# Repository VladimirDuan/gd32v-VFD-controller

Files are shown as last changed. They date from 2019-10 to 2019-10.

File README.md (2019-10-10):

# gd32v-VFD-controller

## The HNV-12SS62 VFD screen:

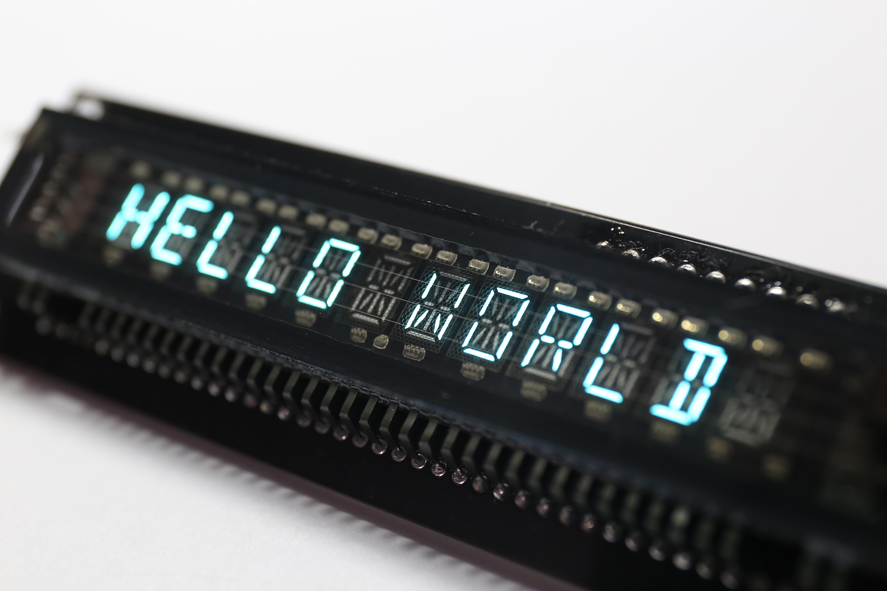
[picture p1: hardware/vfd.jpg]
VFD


## GD32V rv32imac microcontroller:

VFD_MCU

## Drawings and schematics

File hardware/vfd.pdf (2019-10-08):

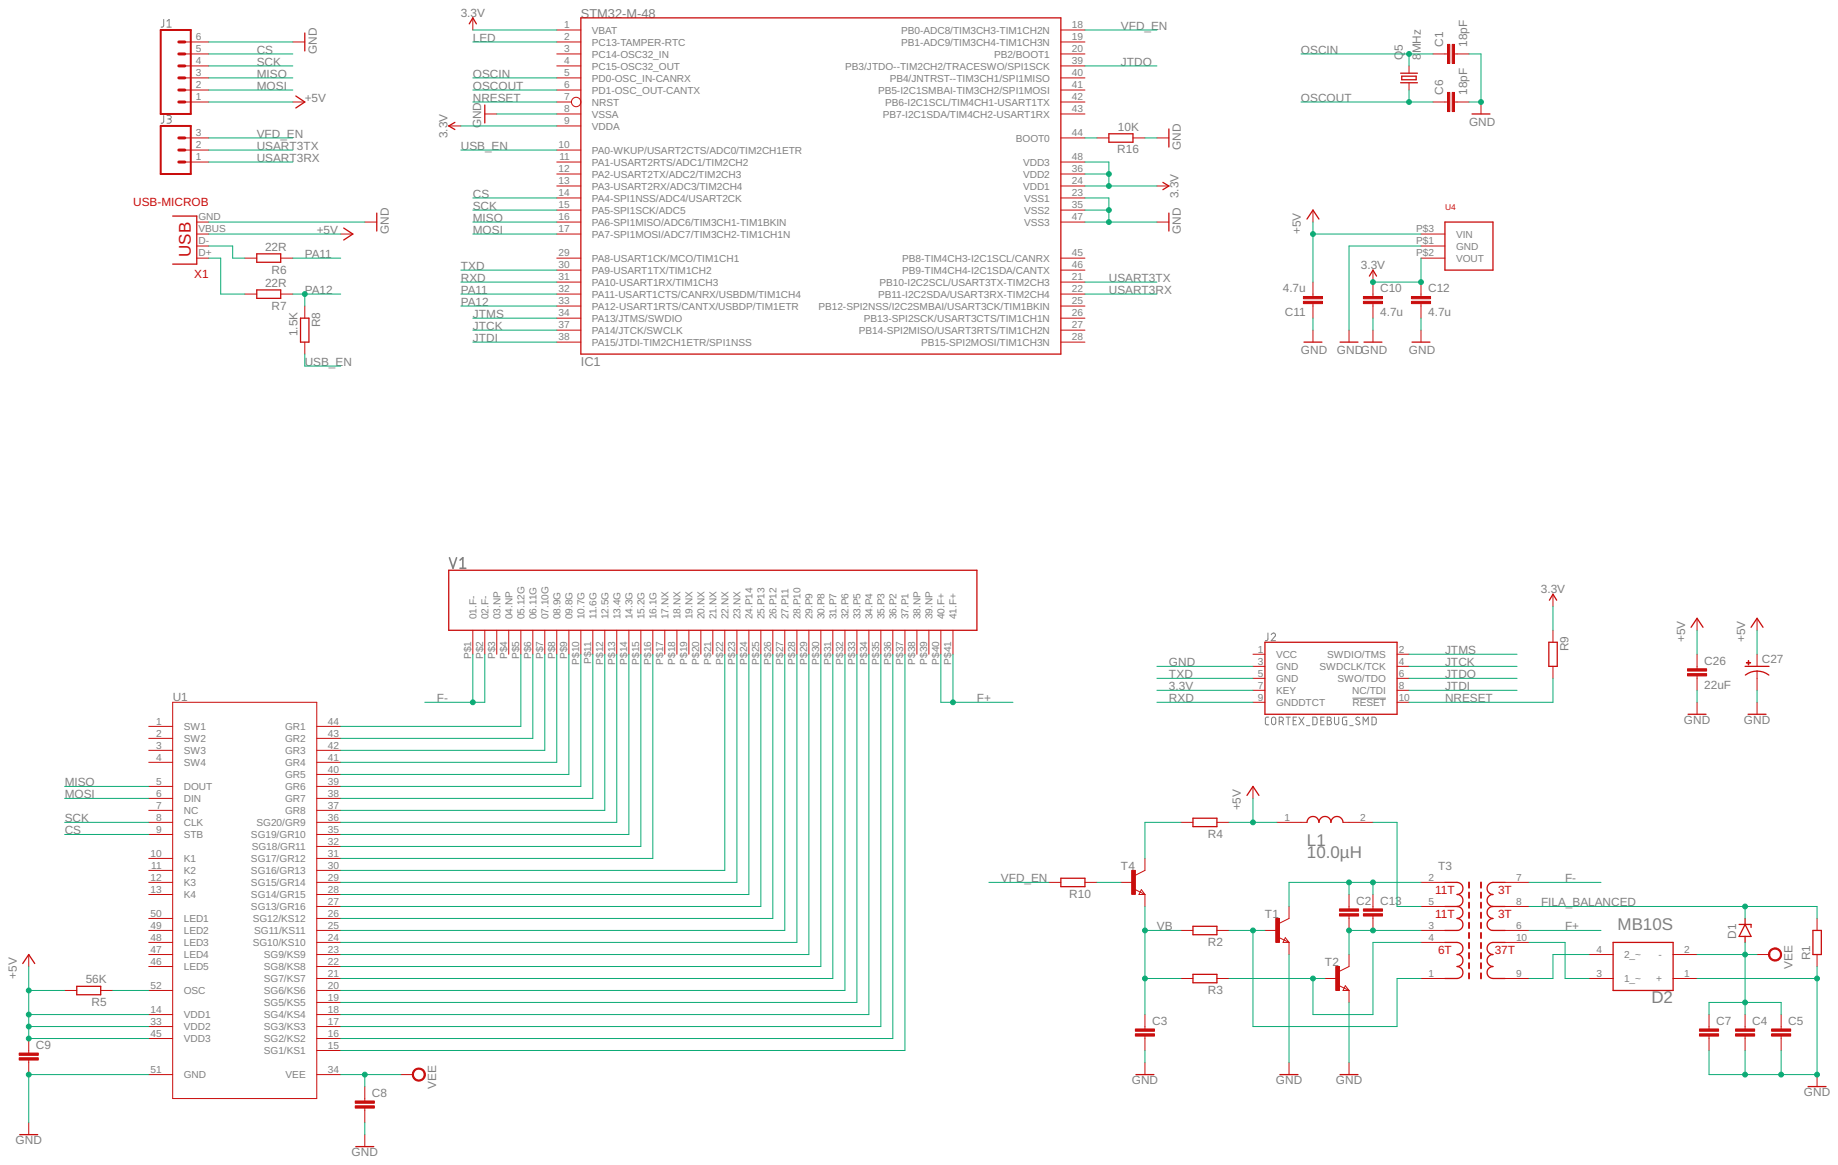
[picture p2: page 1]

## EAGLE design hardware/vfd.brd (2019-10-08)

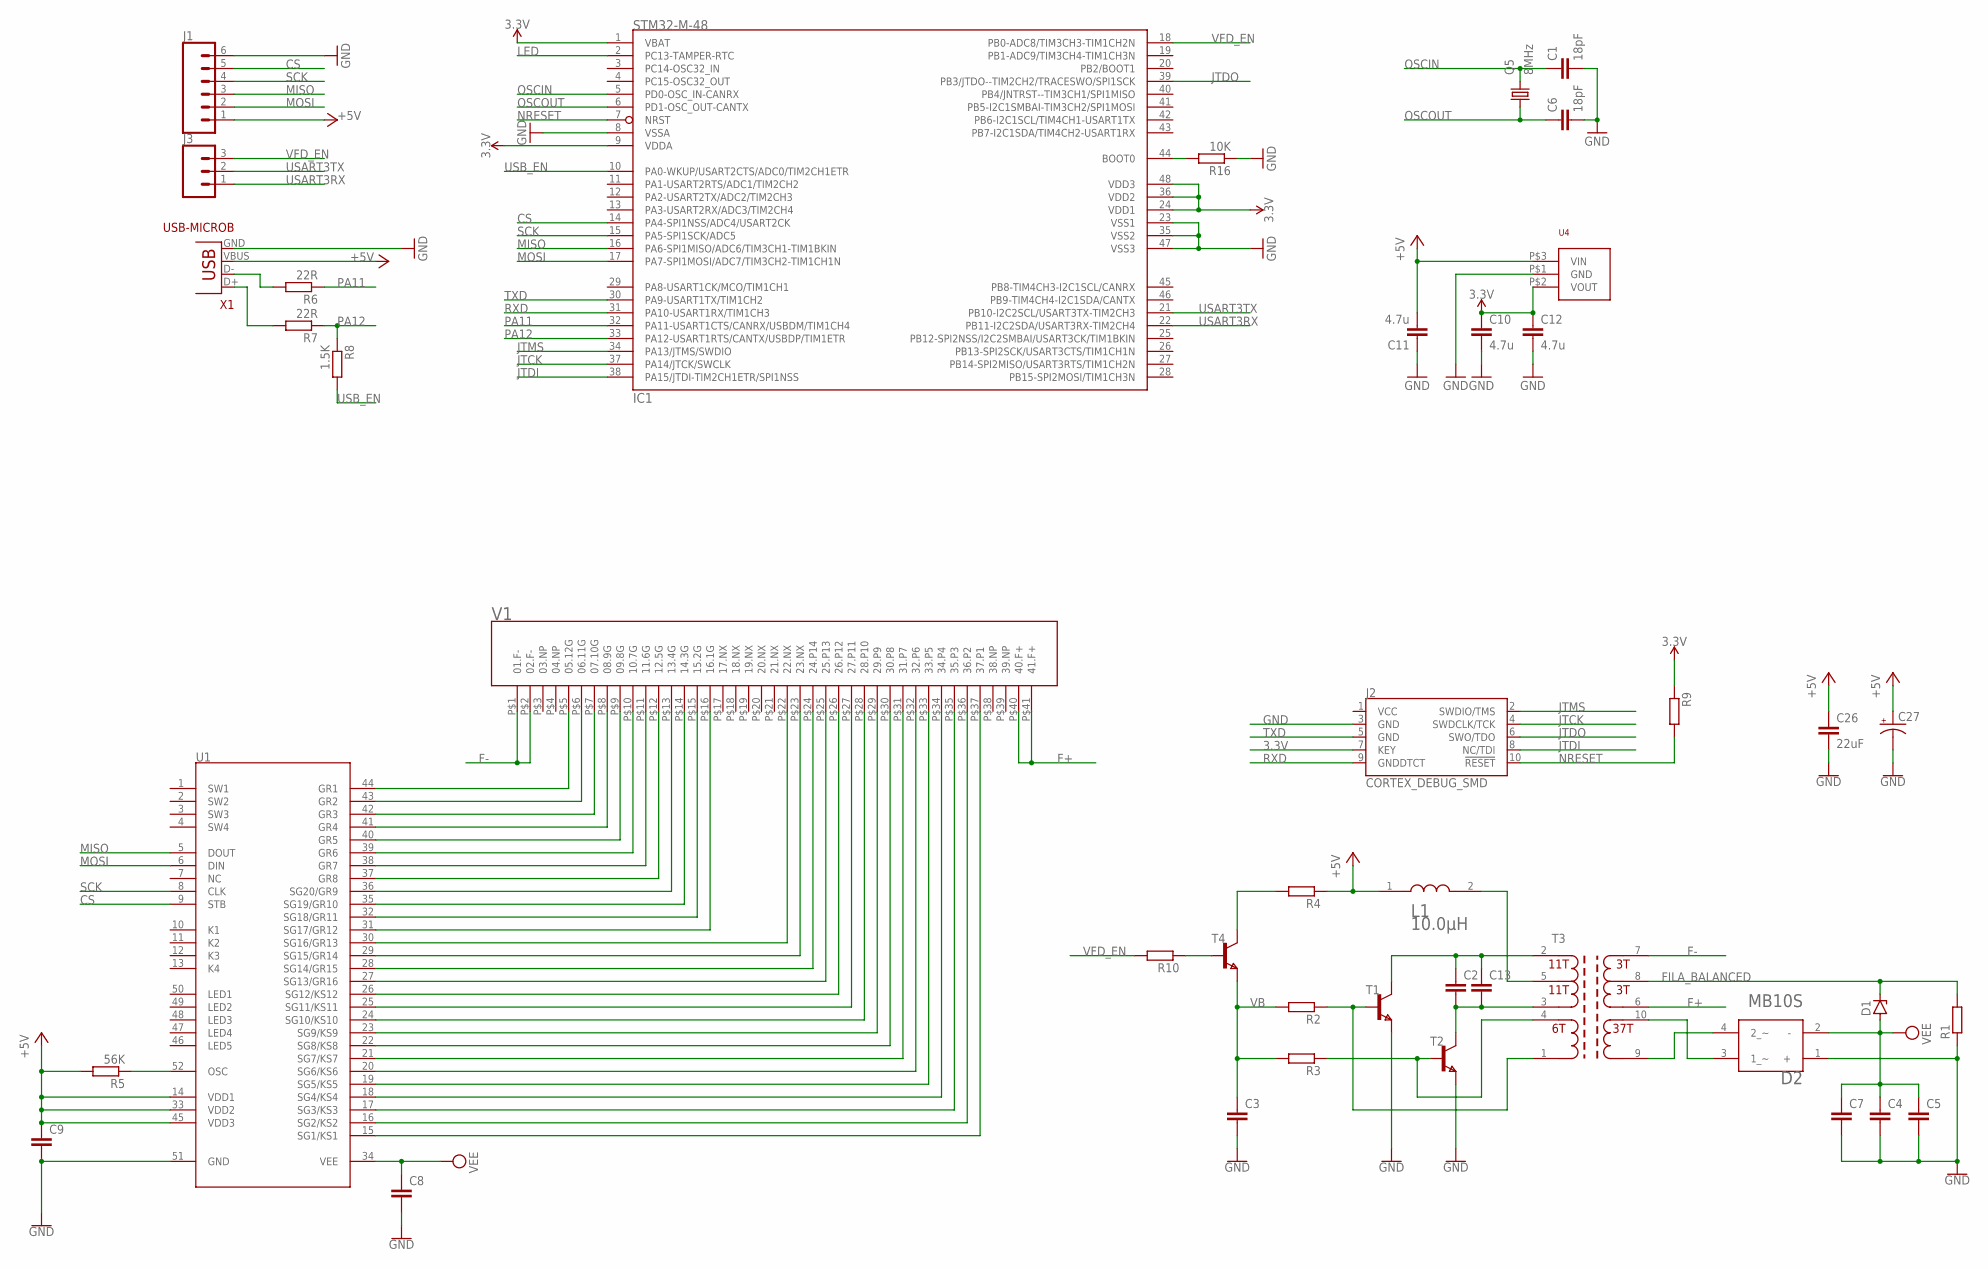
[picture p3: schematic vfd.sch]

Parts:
C1, C6: 18pF; C0603
C2, C13: C-EUC1206; C1206
C3, C4, C5, C7, C8, C9: C-EUC0805; C0805
C10, C11, C12: 4.7u; 0805
C26: 22uF; C1206
C27: CPOL-US153CLV-0807; 153CLV-0807
D1: ZENER-DIODESOD80C; SOD80C
D2: ON_SEMI_MB10SON_SEMI_MB10S_0_0; ON_SEMI_MB10S_0
IC1: STM32-M-48; LQFP48
J1: CONN_06NO_SILK_FEMALE_PTH; 1X06_NO_SILK
J2: CORTEX_DEBUG_SMD; SAMTECH_FTSH-105-01
J3: CONN_031X03_NO_SILK; 1X03_NO_SILK
L1: TDK_SLF7045T-100M1R3-PF; ASWPA8050
Q5: 8MHz; 3.2X2.5_KX-7
R1, R2, R3, R4, R9, R10: R-EU_R0603; R0603
R5: 56K; R0603
R6, R7: 22R; R0603
R8: 1.5K; R0603
R16: 10K; R0603
T1, T2, T4: NPNSOT23; SOT-23
T3: TRANS_VFD_ER10P5; ER10P5
U1: PT6311B; QFP52_SOT379-1
U4: MCP1703SOT-3.3V; SOT-23A
V1: VFD_12SS62; 12SS62
X1: USB-MICROB

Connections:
3.3V: C10.1, C12.1, IC1.1 (VBAT), IC1.9 (VDDA), IC1.24 (VDD1), IC1.36 (VDD2), IC1.48 (VDD3), J2.7 (KEY), R9.1, U4.P$2 (VOUT)
+5V: C9.1, C11.2, C26.1, C27.+, J1.1, L1.1, R4.1, R5.2, U1.14 (VDD1), U1.33 (VDD2), U1.45 (VDD3), U4.P$3 (VIN), X1.VBUS
CS: IC1.14 (PA4-SPI1NSS/ADC4/USART2CK), J1.5, U1.9 (STB)
F+: T3.6, V1.P$40 (40.F+), V1.P$41 (41.F+)
F-: T3.7, V1.P$1 (01.F-), V1.P$2 (02.F-)
FILA_BALANCED: D1.C, R1.2, T3.8
GND: C1.2, C3.2, C4.2, C5.2, C6.2, C7.2, C8.2, C9.2, C10.2, C11.1, C12.2, C26.2, C27.-, D2.1 (+), IC1.8 (VSSA), IC1.23 (VSS1), IC1.35 (VSS2), IC1.47 (VSS3), J1.6, J2.3 (GND), R1.1, R16.1, T1.2 (E), T2.2 (E), U1.51 (GND), U4.P$1 (GND), X1.GND
JTCK: IC1.37 (PA14/JTCK/SWCLK), J2.4 (SWDCLK/TCK)
JTDI: IC1.38 (PA15/JTDI-TIM2CH1ETR/SPI1NSS), J2.8 (NC/TDI)
JTDO: IC1.39 (PB3/JTDO--TIM2CH2/TRACESWO/SPI1SCK), J2.6 (SWO/TDO)
JTMS: IC1.34 (PA13/JTMS/SWDIO), J2.2 (SWDIO/TMS)
LED: IC1.2 (PC13-TAMPER-RTC)
MISO: IC1.16 (PA6-SPI1MISO/ADC6/TIM3CH1-TIM1BKIN), J1.3, U1.5 (DOUT)
MOSI: IC1.17 (PA7-SPI1MOSI/ADC7/TIM3CH2-TIM1CH1N), J1.2, U1.6 (DIN)
unnamed: U1.44 (GR1), V1.P$5 (05.12G)
unnamed: U1.43 (GR2), V1.P$6 (06.11G)
unnamed: U1.42 (GR3), V1.P$7 (07.10G)
unnamed: U1.41 (GR4), V1.P$8 (08.9G)
unnamed: U1.40 (GR5), V1.P$9 (09.8G)
unnamed: U1.39 (GR6), V1.P$10 (10.7G)
unnamed: U1.38 (GR7), V1.P$11 (11.6G)
unnamed: U1.37 (GR8), V1.P$12 (12.5G)
unnamed: U1.36 (SG20/GR9), V1.P$13 (13.4G)
unnamed: U1.35 (SG19/GR10), V1.P$14 (14.3G)
unnamed: U1.32 (SG18/GR11), V1.P$15 (15.2G)
unnamed: U1.31 (SG17/GR12), V1.P$16 (16.1G)
unnamed: U1.15 (SG1/KS1), V1.P$37 (37.P1)
unnamed: U1.16 (SG2/KS2), V1.P$36 (36.P2)
unnamed: U1.17 (SG3/KS3), V1.P$35 (35.P3)
unnamed: U1.18 (SG4/KS4), V1.P$34 (34.P4)
unnamed: U1.19 (SG5/KS5), V1.P$33 (33.P5)
unnamed: U1.20 (SG6/KS6), V1.P$32 (32.P6)
unnamed: U1.21 (SG7/KS7), V1.P$31 (31.P7)
unnamed: U1.22 (SG8/KS8), V1.P$30 (30.P8)
unnamed: U1.23 (SG9/KS9), V1.P$29 (29.P9)
unnamed: U1.24 (SG10/KS10), V1.P$28 (28.P10)
unnamed: U1.25 (SG11/KS11), V1.P$27 (27.P11)
unnamed: U1.26 (SG12/KS12), V1.P$26 (26.P12)
unnamed: U1.27 (SG13/GR16), V1.P$25 (25.P13)
unnamed: U1.28 (SG14/GR15), V1.P$24 (24.P14)
unnamed: U1.29 (SG15/GR14), V1.P$23 (23.NX)
unnamed: U1.30 (SG16/GR13), V1.P$22 (22.NX)
unnamed: R6.2, X1.D-
unnamed: R7.2, X1.D+
unnamed: R4.2, T4.1 (C)
unnamed: R10.1, T4.3 (B)
unnamed: R5.1, U1.52 (OSC)
unnamed: D2.4 (2_~), T3.9
unnamed: D2.3 (1_~), T3.10
unnamed: L1.2, T3.5
unnamed: C2.1, C13.1, T1.1 (C), T3.2
unnamed: C2.2, C13.2, T2.1 (C), T3.3
unnamed: R3.1, T2.3 (B), T3.4
unnamed: R2.1, T1.3 (B), T3.1
unnamed: IC1.44 (BOOT0), R16.2
NRESET: IC1.7 (NRST), J2.10 (!RESET), R9.2
OSCIN: C1.1, IC1.5 (PD0-OSC_IN-CANRX), Q5.3 (2)
OSCOUT: C6.1, IC1.6 (PD1-OSC_OUT-CANTX), Q5.1
PA11: IC1.32 (PA11-USART1CTS/CANRX/USBDM/TIM1CH4), R6.1
PA12: IC1.33 (PA12-USART1RTS/CANTX/USBDP/TIM1ETR), R7.1, R8.1
RXD: IC1.31 (PA10-USART1RX/TIM1CH3), J2.9 (GNDDTCT)
SCK: IC1.15 (PA5-SPI1SCK/ADC5), J1.4, U1.8 (CLK)
TXD: IC1.30 (PA9-USART1TX/TIM1CH2), J2.5 (GND)
USART3RX: IC1.22 (PB11-I2C2SDA/USART3RX-TIM2CH4), J3.1
USART3TX: IC1.21 (PB10-I2C2SCL/USART3TX-TIM2CH3), J3.2
USB_EN: IC1.10 (PA0-WKUP/USART2CTS/ADC0/TIM2CH1ETR), R8.2
VB: C3.1, R2.2, R3.2, T4.2 (E)
VEE: C4.1, C5.1, C7.1, C8.1, D1.A, D2.2 (-), U1.34 (VEE)
VFD_EN: IC1.18 (PB0-ADC8/TIM3CH3-TIM1CH2N), J3.3, R10.2

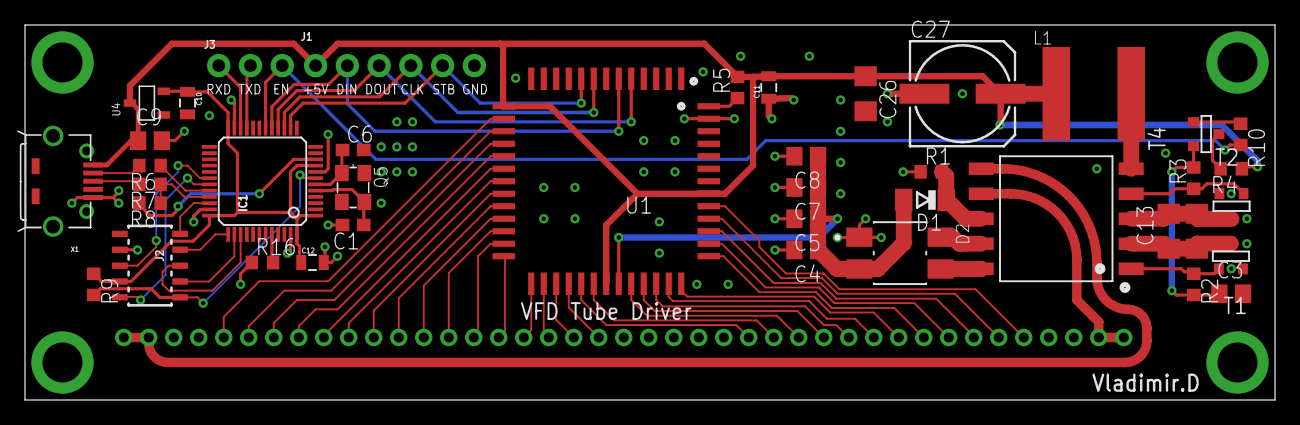
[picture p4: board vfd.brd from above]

Board: 2 copper layers, 100.0 x 30.0 mm, 42 parts (1 on the bottom side), 68 nets.

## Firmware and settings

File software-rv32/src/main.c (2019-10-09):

/*!
    \file  main.c
    \brief running led
    
    \version 2019-6-5, V1.0.0, firmware for GD32VF103
*/

/*
    Copyright (c) 2019, GigaDevice Semiconductor Inc.

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
    1. Redistributions of source code must retain the above copyright notice, this 
       list of conditions and the following disclaimer.
    2. Redistributions in binary form must reproduce the above copyright notice, 
       this list of conditions and the following disclaimer in the documentation 
       and/or other materials provided with the distribution.
    3. Neither the name of the copyright holder nor the names of its contributors 
       may be used to endorse or promote products derived from this software without 
       specific prior written permission.

    THIS SOFTWARE IS PROVIDED BY THE COPYRIGHT HOLDERS AND CONTRIBUTORS "AS IS" 
AND ANY EXPRESS OR IMPLIED WARRANTIES, INCLUDING, BUT NOT LIMITED TO, THE IMPLIED 
WARRANTIES OF MERCHANTABILITY AND FITNESS FOR A PARTICULAR PURPOSE ARE DISCLAIMED. 
IN NO EVENT SHALL THE COPYRIGHT HOLDER OR CONTRIBUTORS BE LIABLE FOR ANY DIRECT, 
INDIRECT, INCIDENTAL, SPECIAL, EXEMPLARY, OR CONSEQUENTIAL DAMAGES (INCLUDING, BUT 
NOT LIMITED TO, PROCUREMENT OF SUBSTITUTE GOODS OR SERVICES; LOSS OF USE, DATA, OR 
PROFITS; OR BUSINESS INTERRUPTION) HOWEVER CAUSED AND ON ANY THEORY OF LIABILITY, 
WHETHER IN CONTRACT, STRICT LIABILITY, OR TORT (INCLUDING NEGLIGENCE OR OTHERWISE) 
ARISING IN ANY WAY OUT OF THE USE OF THIS SOFTWARE, EVEN IF ADVISED OF THE POSSIBILITY 
OF SUCH DAMAGE.
*/

#include "gd32vf103.h"
#include "systick.h"
#include <stdio.h>
#include <string.h>
#include "spi.h"
#include "drv_usb_hw.h"
#include "iap_core.h"
#include "riscv_encoding.h"

unsigned char disp_mem[64] = "#UNDEFINED# ";

usb_core_driver USB_OTG_dev = 
{
    .dev = {
        .desc = {
            .dev_desc       = (uint8_t *)&device_descripter,
            .config_desc    = (uint8_t *)&configuration_descriptor,
            .strings        = usbd_strings,
        }
    }
};

pAppFunction application;

extern uint8_t usbd_serial_string[];
void serial_string_create(void);

uint16_t calculate_segments_14(uint8_t character);
uint16_t display_seg(unsigned char c);
uint16_t display_string(unsigned char* str);

/*!
    \brief      main function
    \param[in]  none
    \param[out] none
    \retval     none
*/
int main(void)
{
    
    eclic_global_interrupt_enable();

    eclic_priority_group_set(ECLIC_PRIGROUP_LEVEL2_PRIO2);
  
    usb_timer_init();

    /* peripheral clock enable */
    rcu_config();
    rcu_periph_clock_enable(RCU_USART0);
    /* GPIO configure */
    gpio_config();

    /* connect port to USARTx_Tx */
    gpio_init(GPIOA, GPIO_MODE_AF_PP, GPIO_OSPEED_50MHZ, GPIO_PIN_9);
    /* connect port to USARTx_Rx */
    gpio_init(GPIOA, GPIO_MODE_IN_FLOATING, GPIO_OSPEED_50MHZ, GPIO_PIN_10);

    
    /* USART configure */
    usart_deinit(USART0);
    usart_baudrate_set(USART0, 115200U);
    usart_word_length_set(USART0, USART_WL_8BIT);
    usart_stop_bit_set(USART0, USART_STB_1BIT);
    usart_parity_config(USART0, USART_PM_NONE);
    usart_hardware_flow_rts_config(USART0, USART_RTS_DISABLE);
    usart_hardware_flow_cts_config(USART0, USART_CTS_DISABLE);
    usart_receive_config(USART0, USART_RECEIVE_ENABLE);
    usart_transmit_config(USART0, USART_TRANSMIT_ENABLE);
    usart_enable(USART0);

    /* SPI configure */
    spi_config();

    spi_enable(SPI0);
    stb_high();
    
    delay_1ms(2000);

    GPIO_BOP(GPIOB) = GPIO_PIN_0; // ROYER EN
    
    delay_1ms(1000);

    
    stb_low();
    spi_send(0b01000000);
    stb_high();

    stb_low();
    spi_send(0b11000000);

    display_seg(' ');
    display_seg('D');
    display_seg('L');
    display_seg('R');
    display_seg('O');
    display_seg('W');
    display_seg(' ');
    display_seg('O');
    display_seg('L');
    display_seg('L');
    display_seg('E');
    display_seg('H');

    stb_high();

    stb_low();
    spi_send(0b00001011);   // 12 digits, 16 segments
    stb_high();

    stb_low();
    spi_send(0b10001111);   // display on
    stb_high();
    
    GPIO_BOP(GPIOA) = GPIO_PIN_0;   // USB ENABLE
    
    /* configure USB clock */
    usb_rcu_config();

    serial_string_create();

    usb_intr_config();

    usbd_init (&USB_OTG_dev, USB_CORE_ENUM_FS, &usbd_hid_cb);

    /* check if USB device is enumerated successfully */
    while (USB_OTG_dev.dev.cur_status != USBD_CONFIGURED) {
    }

    while (1)
    {
        //delay_1ms(2000);
        display_string("            ");
        display_string("D           ");
        display_string("LD          ");
        display_string("RLD         ");
        display_string("ORLD        ");
        display_string("WORLD       ");
        display_string(" WORLD      ");
        display_string("O WORLD     ");
        display_string("LO WORLD    ");
        display_string("LLO WORLD   ");
        display_string("ELLO WORLD  ");
        display_string("HELLO WORLD ");
        display_string(" HELLO WORLD");
        display_string("  HELLO WORL");
        display_string("   HELLO WOR");
        display_string("    HELLO WO");
        display_string("     HELLO W");
        display_string("      HELLO ");
        display_string("       HELLO");
        display_string("        HELL");
        display_string("         HEL");
        display_string("          HE");
        display_string("           H");
        display_string("            ");
        display_string("           H");
        display_string("          HE");
        display_string("         HEL");
        display_string("        HELL");
        display_string("       HELLO");
        display_string("      HELLO ");
        display_string("     HELLO W");
        display_string("    HELLO WO");
        display_string("   HELLO WOR");
        display_string("  HELLO WORL");
        display_string(" HELLO WORLD");
        display_string("HELLO WORLD ");
        display_string("ELLO WORLD  ");
        display_string("LLO WORLD   ");
        display_string("LO WORLD    ");
        display_string("O WORLD     ");
        display_string(" WORLD      ");
        display_string("WORLD       ");
        display_string("ORLD        ");
        display_string("RLD         ");
        display_string("LD          ");
        display_string("D           ");
        display_string("            ");

            // TODO: fetch real information from pc by usb-hid.
        display_string("** CPU-41 **");
        delay_1ms(2000);
        display_string("** MEM-28 **");
        delay_1ms(2000);

        while(1)
        {
            display_string(disp_mem);
            delay_1ms(10);
        }
        /*
        delay_1ms(500);
        //GPIO_BC(GPIOB) = GPIO_PIN_0; // ROYER DEN   
        delay_1ms(1000);
        
        display_string("VFD ENABLED");
        GPIO_BOP(GPIOB) = GPIO_PIN_0; // ROYER EN   
        */
    }
}

/* retarget the C library printf function to the USART */
int _put_char(int ch)
{
    usart_data_transmit(USART0, (uint8_t) ch );
    while ( usart_flag_get(USART0, USART_FLAG_TBE)== RESET){
    }

    return ch;
}

uint16_t display_seg(unsigned char c)
{
    uint16_t i = calculate_segments_14(c);
    
    spi_send(i&0xff);
    spi_send((i>>8)&0xff);
    spi_send(0b00000000);
}

uint16_t display_string(unsigned char* str)
{
    unsigned char newstr[12];
    strcpy(newstr,str);
    for(uint8_t i = 0; i < 12; i++)
    {
        if(newstr[i] == 0)
        {
            newstr[i] = ' ';
        }
    }
    stb_low();
    spi_send(0b11000000);

    display_seg(newstr[11]);
    display_seg(newstr[10]);
    display_seg(newstr[9]);
    display_seg(newstr[8]);
    display_seg(newstr[7]);
    display_seg(newstr[6]);
    display_seg(newstr[5]);
    display_seg(newstr[4]);
    display_seg(newstr[3]);
    display_seg(newstr[2]);
    display_seg(newstr[1]);
    display_seg(newstr[0]);

    stb_high();
        delay_1ms(100);
}


/*!
    \brief      create the serial number string descriptor
    \param[in]  none
    \param[out] none
    \retval     none
*/
void  serial_string_create (void)
{
    uint32_t device_serial = *(uint32_t*)DEVICE_ID;

    if (0 != device_serial) {
        usbd_serial_string[2] = (uint8_t)device_serial;
        usbd_serial_string[3] = (uint8_t)(device_serial >> 8);
        usbd_serial_string[4] = (uint8_t)(device_serial >> 16);
        usbd_serial_string[5] = (uint8_t)(device_serial >> 24);
    }
}

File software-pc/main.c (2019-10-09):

#ifdef WIN32
#include <windows.h>
#endif
#include <stdio.h>
#include <stdlib.h>
#include "hidapi.h"
#include "os_related.h"
 

#define MAX_STR 255

int main(int argc, char* argv[])
{
	int res;
	unsigned char buf[65];
	wchar_t wstr[MAX_STR];
	hid_device *handle;
	int i;

	// Initialize the hidapi library
	res = hid_init();

	// Open the device using the VID, PID,
	// and optionally the Serial number.
	handle = hid_open(0x28E9, 0x0C8C, NULL);

	// Read the Manufacturer String
	res = hid_get_manufacturer_string(handle, wstr, MAX_STR);
	wprintf(L"Manufacturer String: %s\n", wstr);

	// Read the Product String
	res = hid_get_product_string(handle, wstr, MAX_STR);
	wprintf(L"Product String: %s\n", wstr);

	// Read the Serial Number String
	res = hid_get_serial_number_string(handle, wstr, MAX_STR);
	wprintf(L"Serial Number String: (%d) %s\n", wstr[0], wstr);

	// Read Indexed String 1
	res = hid_get_indexed_string(handle, 1, wstr, MAX_STR);
	wprintf(L"Indexed String 1: %s\n", wstr);

	// Toggle LED (cmd 0x80). The first byte is the report number (0x01).
	buf[0] = 0x01;
	sprintf(buf+1,"HELLO WORLD*");
	
	res = hid_write(handle, buf, 65);

	while(1)
	{
			Initialize();
			Sleep(1000);
			int cpu_usage = GetCPUUseRate();
			sprintf(buf+1,"** CPU-%02d **", cpu_usage);
			res = hid_write(handle, buf, 65);
	}

	// Finalize the hidapi library
	res = hid_exit();

	return 0;
}

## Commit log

2019-10-08 Add design files.
    [vfd.brd, vfd.sch]
2019-10-08 Add some display patterns.
    [vfd.brd, vfd.sch]
2019-10-09 add usb-hid.
    [vfd.brd, vfd.sch]

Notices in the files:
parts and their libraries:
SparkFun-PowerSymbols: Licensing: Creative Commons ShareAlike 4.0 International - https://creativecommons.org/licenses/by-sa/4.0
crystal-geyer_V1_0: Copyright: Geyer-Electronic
